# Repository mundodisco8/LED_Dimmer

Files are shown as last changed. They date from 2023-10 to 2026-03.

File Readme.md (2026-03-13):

# Gruffalo Fairy Light Dimmer

A simple LED light dimmer. My kids love fairy lights, but the ones we have are too bright to use them as sleep lights so I thought about churning up a quick PWM dimmer for them.

It's a simple project with simple goals:

* Do some electronics. I won't get the Noble prize on electronics for this one.
  * Subgoal: doing something in the incredibly sexy [After Dark](https://blog.oshpark.com/2019/10/10/introducing-our-after-dark-black-fr-4-service/) finish from OSH Park.
* Play with the Silicon Labs toolchain. I don't have any FW on my Github.
* Work with encoders. They are tactile and they are nice!
* Think a bit on user interfaces that children can use.
* See how far I can get without getting sued for copyright infringement.

The design acts as a motherboard for another of my projects, a [breakout board for the BGM220P BLE Module](https://github.com/mundodisco8/BGM220P-Breakout).

This is more or less how it looks like. The renders are done with pcb2blender, and it doesn't handle transparent soldermasks yet, so it's not showing the underlying copper base.

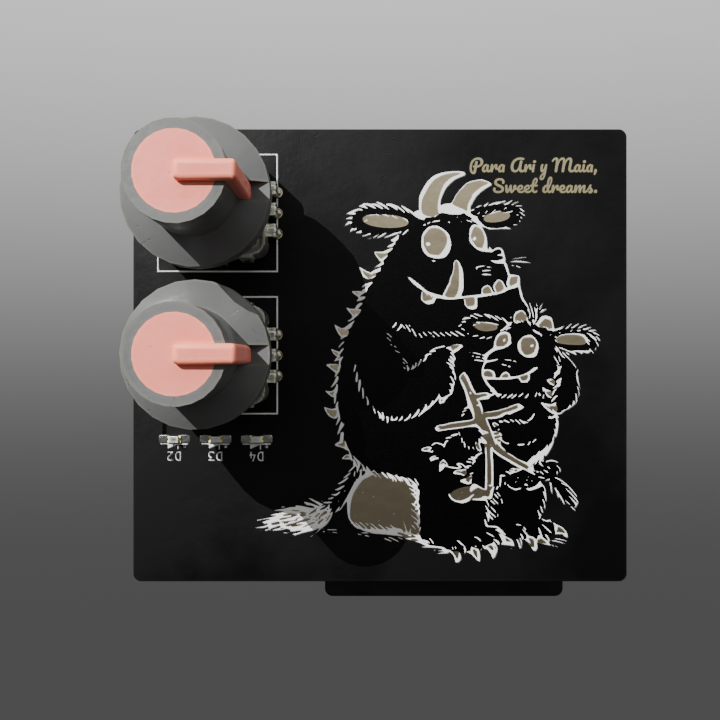
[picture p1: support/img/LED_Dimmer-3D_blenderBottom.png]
Bottom
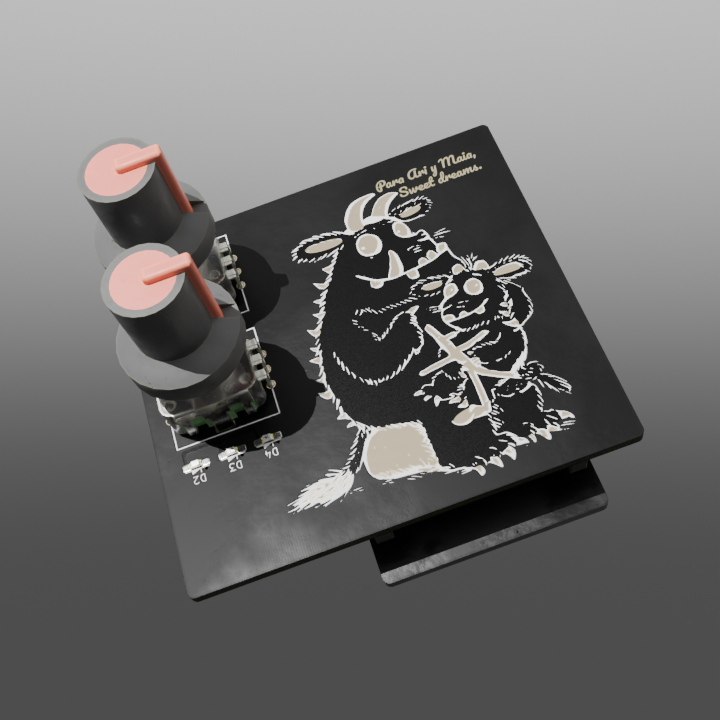
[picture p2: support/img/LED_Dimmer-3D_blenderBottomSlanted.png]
Bottom Slanted


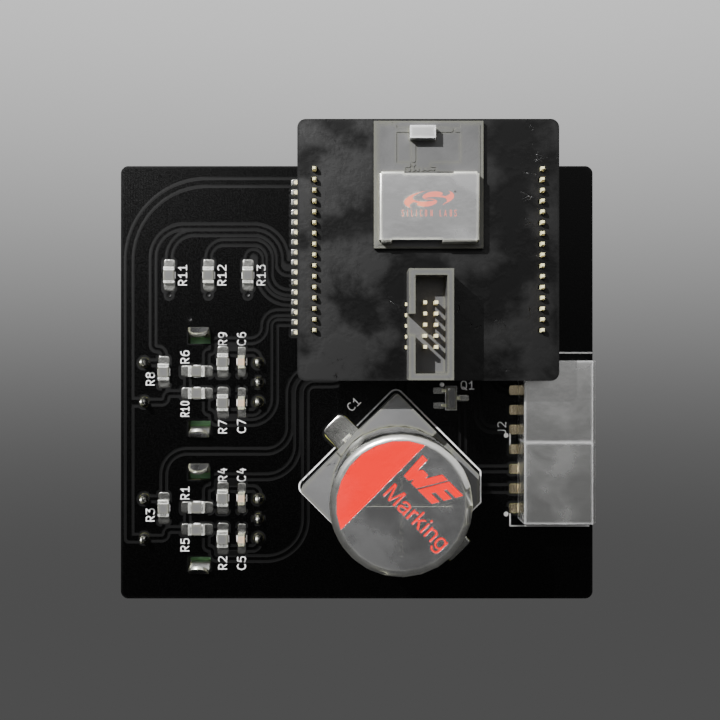
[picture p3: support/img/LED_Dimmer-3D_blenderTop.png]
Top
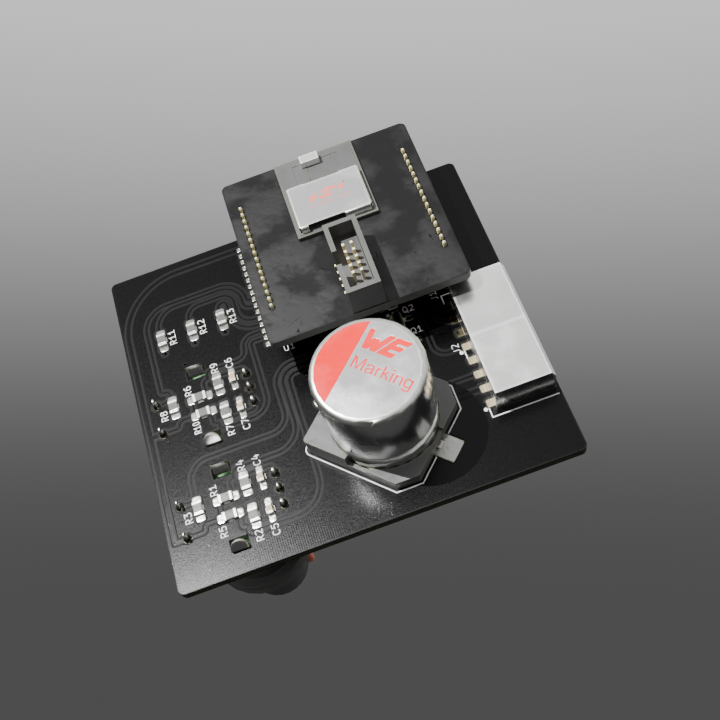
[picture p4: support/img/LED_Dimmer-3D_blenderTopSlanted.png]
Top Slanted


## Working with this project.

It has two elements:

* The hardware is included as a KiCad project. All the files needed are in the `hardware` folder. Make sure you read the [`Readme.md`](hardware/Readme.md) file present there if you want to open it or modify something.
* The firmware is provided as a Simplicity Studio project (Silicon Labs' IDE). You can find it in the `src` folder. Like the HW project, check the [`Readme.md`](src/readme.md) file to get more details about it.

## Tools I'm Using / Stuff I'm Stealing.

Made with:

* KiCad for the HW design, Simplicity Studio / VS Code for the Firmware.
* Unity for unit testing.
* Inkscape, for the art manipulation.
* Fusion360, for 3D model generation, as a source for my Fab layers and for the enclosure.
* Blender + [pcb2blender](https://github.com/30350n/pcb2blender), to generate my renders.
* I'm using [KiBot](https://github.com/INTI-CMNB/KiBot) as the main tool in my CI/CD pipeline.
* I used the Pacifico font in some text elements in the PCB ([link](https://fonts.google.com/specimen/Pacifico))

Things I definitely didn't do:

* The art, taken from [certain children's book authors](https://www.gruffalo.com/).

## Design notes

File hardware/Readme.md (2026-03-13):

# Readme

## LED Dimmer PCB

List of things that are interesting to know in order to work with this project.

* This commit uses KiCad 8.0.5
* It uses an unusual font for some text elements. It's Pacifico ([can be obtained here](https://fonts.google.com/specimen/Pacifico), and a copy is left in the `resources/fonts` folder as KiBot needs it).

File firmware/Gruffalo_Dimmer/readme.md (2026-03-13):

# LED Dimmer Firmware

This folder contains the Firmware project for the LED Dimmer. The project included is targeting a BGM220PWGA Module, but it could be compiled for other SoCs / Modules.

## Getting Started

The project is based on the Empty-SOC example.

It uses the 2024.6.1 SDK and GCC 12.2.1. In my experience, it's not worth to try to update the project to a newer SDK, as it always ends in tears. So one option would be to replicate the toolchain setup (specially the SDK version, the compiler is not that critical), or to get whatever is the latest and then start with a `Bluetooh SoC-Empty` project. If doing the latter, just overwrite your `app.c` with the one from the project, copy the `src` and `inc` folders (just to be specific, the `src/src` and `src/inc` folders) and make sure you add `inc` to the `include` path of the project (left click in the project, `C/C++ Build`, `Settings`, ` GNU ARM C Compiler`, `Includes`, `Include paths (-l)`).

Finally, it's a matter of preference, but I like to set all the warnings in my code, and disable all the warnings in the SDK code (as I can't do much to fix them, really). To do that, left click in the project, properties, C/C++ Build, Settings and in Tool Settings, GNU ARM C Compiler (And Assembler), remove `all warnings` and `extra warnings` and enable `Inhibit all warnings`. Then in my `inc` and `src` folders, and in `app.c`, do the same, but enable the relevant flags. **Do it in this order, or the general changes will inhibit your source code warnings**.

One of the SDK was triggering 70+ Code Analysis warnings (different than GCC warnings). To silence them, check the relevant item in Simplicity Studio settings (Window, Preferences, C/C++, Code Analysis). Double click in the warning to suppress and you can enter a pattern for filenames to be ignored. You have to do it for each static analysis warning, but there aren't that many.

### Importing the project.

The best way to import the project is

## Changes to the Empty Project

### Software Components:

#### Clock Manager

The new SDK didn't configure the clocks of my BLE module correctly and it would assert in the BT initialisation. I changed the `Clock Manager` settings, enabling the `HFXO Settings`, and leaving everything as default (XTAL Mode, 38.4MHz, 140, 50), leaving the `LFXO Settings` disabled, setting the `LFRCO Settings` to `High Precission` and finally, in `Clock Tree Settings`, picking `HXFO` as the `Default Clock Source Selection for HF clock branches` (`LFRCO` for the `LF clock branches`).

#### IO Stream: EUSART

Installed this module to get serial debugging. Set the EUART as you require, and then set the `RX` and `TX` Pins to `PB00` and `PA00` respectively.

#### Log

Used to get nice log output. Configuring it is a matter of preference, so do whatever you prefer here.

#### GPIOINT

Needed to handle the button and rotary interrupts. Doesn't neet to be configured.

#### Timer

The module is already installed, but you can set the number of software timers you need in `Bluetooth Stack Configuration` in `Bluetooth Core`.

#### Bootloader Application Interface / Bluetooth In-Place OTA

Remove them if you don't want to faf around with bootloaders. If I'm changing the software, I will need the device removed to play with it so I might as well leave it with the latest, instead of needing to do BLE updates. Maybe one day I have 20 of these around the house and it makes sense to do OTAs.

#### Rail Utility, PTI

PTI it's a radio debugging feature. I'm not going to use it, but it generates warnings if not configured. Set the `SL_RAIL_UTILITY_PTI` module to `None`.

### Pins

Use the Pin Tool to set:

* UART Logging:
  * PA00 as `EUART0_TX`.
  * PB00 as `EUART0_RX`.
* Encoder 0:
  * PA06 as `GPIO Mode` with `btn0` as `Custom Pin Name`.
  * PA07 as `GPIO Mode` with `quad0_0` as `Custom Pin Name`.
  * PA08 as `GPIO Mode` with `quad0_1` as `Custom Pin Name`.
* Encoder 1:
  * PC04 as `GPIO Mode` with `btn1` as `Custom Pin Name`.
  * PA04 as `GPIO Mode` with `quad1_0` as `Custom Pin Name`.
  * PA05 as `GPIO Mode` with `quad1_1` as `Custom Pin Name`.
* PWM:
  * PC2 as `TIMER0_CC0` with `PWM0` as `Custom Pin Name`
  * PC1
  * PC0

## Designing the GATT Database

The SOC-empty example implements a basic GATT database. GATT definitions (services/characteristics) can be extended using the GATT Configurator, which can be found under Advanced Configurators in the Software Components tab of the Project Configurator. To open the Project Configurator, open the .slcp file of the project.

Opening GATT Configurator

To learn how to use the GATT Configurator, see [UG438: GATT Configurator User’s Guide for Bluetooth SDK v3.x](https://www.silabs.com/documents/public/user-guides/ug438-gatt-configurator-users-guide-sdk-v3x.pdf).

## Responding to Bluetooth Events

A Bluetooth application is event driven. The Bluetooth stack generates events e.g., when a remote device connects or disconnects or when it writes a characteristic in the local GATT database. The application has to handle these events in the `sl_bt_on_event()` function. The prototype of this function is implemented in *app.c*. To handle more events, the switch-case statement of this function is to be extended. For the list of Bluetooth events, see the online [Bluetooth API Reference](https://docs.silabs.com/bluetooth/latest/).

## Implementing Application Logic

Additional application logic has to be implemented in the `app_init()` and `app_process_action()` functions. Find the definitions of these functions in *app.c*. The `app_init()` function is called once when the device is booted, and `app_process_action()` is called repeatedly in a while(1) loop. For example, you can poll peripherals in this function. To save energy and to have this function called at specific intervals only, for example once every second, use the services of the [Sleeptimer](https://docs.silabs.com/gecko-platform/latest/service/api/group-sleeptimer). If you need a more sophisticated application, consider using RTOS (see [AN1260: Integrating v3.x Silicon Labs Bluetooth Applications with Real-Time Operating Systems](https://www.silabs.com/documents/public/application-notes/an1260-integrating-v3x-bluetooth-applications-with-rtos.pdf)).

## Features Already Added to the SOC-Empty Application

The SOC-Empty application is ***almost*** empty. It implements a basic application to demonstrate how to handle events, how to use the GATT database, and how to add software components.

* A simple application is implemented in the event handler function that starts advertising on boot (and on connection_closed event). This makes it possible for remote devices to find the device and connect to it.
* A simple GATT database is defined by adding Generic Access and Device Information services. This makes it possible for remote devices to read out some basic information such as the device name.
* The OTA DFU software component is added, which extends both the event handlers (see *sl_ota_dfu.c*) and the GATT database (see *ota_dfu.xml*). This makes it possible to make Over-The-Air Device-Firmware-Upgrade without any additional application code.

## Testing the SOC-Empty Application

As described above, an empty example does nothing except advertising and letting other devices connect and read its basic GATT database. To test this feature, do the following:

1. Build and flash the SoC-Empty example to your device.
2. Make sure a bootloader is installed. See the Troubleshooting section.
3. Download the **EFR Connect** smartphone app, available on [iOS](https://apps.apple.com/us/app/efr-connect/id1030932759) and [Android](https://play.google.com/store/apps/details?id=com.siliconlabs.bledemo).
4. Open the app and choose the Bluetooth Browser.
   EFR Connect start screen
5. Now you should find your device advertising as "Empty Example". Tap **Connect**.
   Bluetooth Browser
6. The connection is opened, and the GATT database is automatically discovered. Find the device name characteristic under Generic Access service and try to read out the device name.
   GATT database of the device

## Troubleshooting

### Bootloader Issues

Note that Example Projects do not include a bootloader. However, Bluetooth-based Example Projects expect a bootloader to be present on the device in order to support device firmware upgrade (DFU). To get your application to work, you should either
- flash the proper bootloader or
- remove the DFU functionality from the project.

**If you do not wish to add a bootloader**, then remove the DFU functionality by uninstalling the *Bootloader Application Interface* software component -- and all of its dependants. This will automatically put your application code to the start address of the flash, which means that a bootloader is no longer needed, but also that you will not be able to upgrade your firmware.

**If you want to add a bootloader**, then either
- Create a bootloader project, build it and flash it to your device. Note that different projects expect different bootloaders:
  - for NCP and RCP projects create a *BGAPI UART DFU* type bootloader
  - for SoC projects on Series 2 devices create a *Bluetooth Apploader OTA DFU* type bootloader

- or run a precompiled Demo on your device from the Launcher view before flashing your application. Precompiled demos flash both bootloader and application images to the device. Flashing your own application image after the demo will overwrite the demo application but leave the bootloader in place.
  - For NCP and RCP projects, flash the *Bluetooth - NCP* demo.
  - For SoC projects, flash the *Bluetooth - SoC Thermometer* demo.

**Important Notes:**
- when you flash your application image to the device, use the *.hex* or *.s37* output file. Flashing *.bin* files may overwrite (erase) the bootloader.

- On Series 2 devices SoC example projects require a *Bluetooth Apploader OTA DFU* type bootloader by default. This bootloader needs a lot of flash space and does not fit into the regular bootloader area, hence the application start address must be shifted. This shift is automatically done by the *Apploader Support for Applications* software component, which is installed by default. If you want to use any other bootloader type, you should remove this software component in order to shift the application start address back to the end of the regular bootloader area. Note, that in this case you cannot do OTA DFU with Apploader, but you can still implement application-level OTA DFU by installing the *Application OTA DFU* software component instead of *In-place OTA DFU*.

For more information on bootloaders, see [UG103.6: Bootloader Fundamentals](https://www.silabs.com/documents/public/user-guides/ug103-06-fundamentals-bootloading.pdf) and [UG489: Silicon Labs Gecko Bootloader User's Guide for GSDK 4.0 and Higher](https://cn.silabs.com/documents/public/user-guides/ug489-gecko-bootloader-user-guide-gsdk-4.pdf).

### Programming the Radio Board

Before programming the radio board mounted on the mainboard, make sure the power supply switch is in the AEM position (right side) as shown below.

Radio board power supply switch

## Resources

[Bluetooth Documentation](https://docs.silabs.com/bluetooth/latest/)

[UG103.14: Bluetooth LE Fundamentals](https://www.silabs.com/documents/public/user-guides/ug103-14-fundamentals-ble.pdf)

[QSG169: Bluetooth SDK v3.x Quick Start Guide](https://www.silabs.com/documents/public/quick-start-guides/qsg169-bluetooth-sdk-v3x-quick-start-guide.pdf)

[UG434: Silicon Labs Bluetooth ® C Application Developer's Guide for SDK v3.x](https://www.silabs.com/documents/public/user-guides/ug434-bluetooth-c-soc-dev-guide-sdk-v3x.pdf)

[Bluetooth Training](https://www.silabs.com/support/training/bluetooth)

## Report Bugs & Get Support

You are always encouraged and welcome to report any issues you found to us via [Silicon Labs Community](https://www.silabs.com/community).

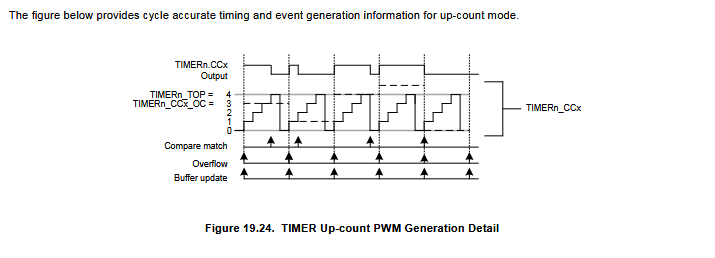
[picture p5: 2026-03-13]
doc/PWM And Breathe Effect/img/PWMCycleAccurate.png

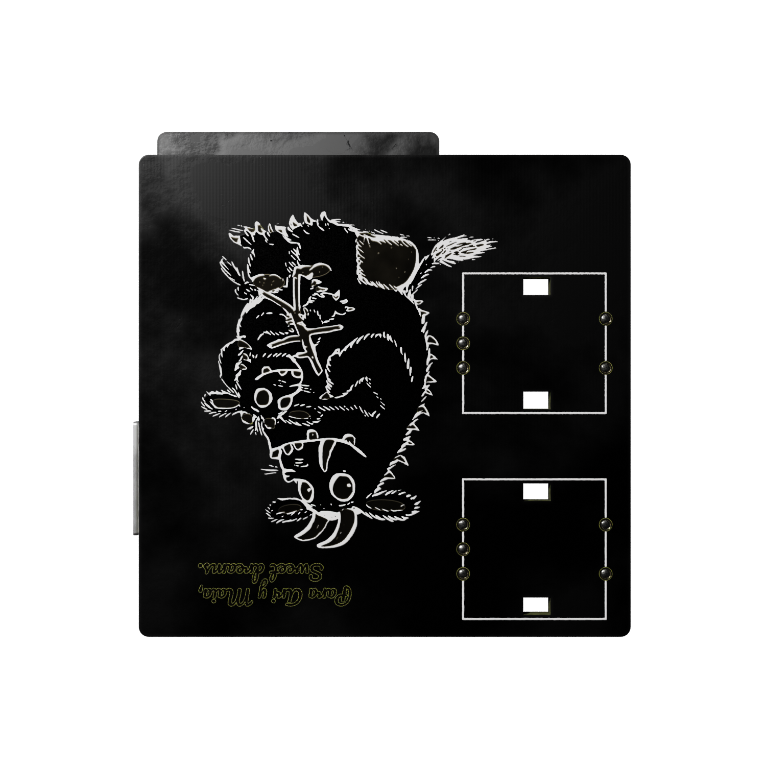
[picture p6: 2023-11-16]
support/img/LED_Dimmer-3D_blenderBottom_BottomTexture.png

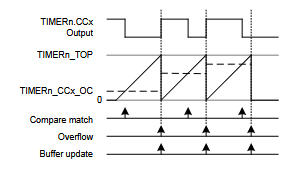
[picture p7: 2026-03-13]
doc/PWM And Breathe Effect/img/PWMGraph.png

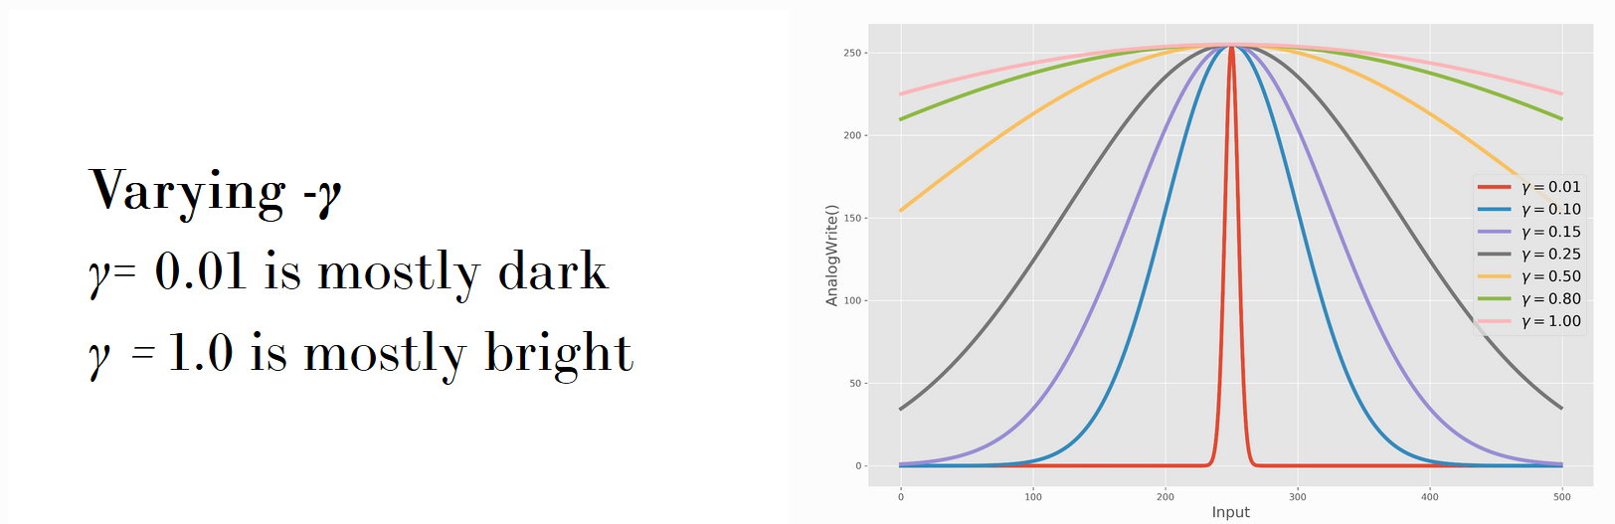
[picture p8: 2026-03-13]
doc/PWM And Breathe Effect/img/GaussianBreatheGamma.png

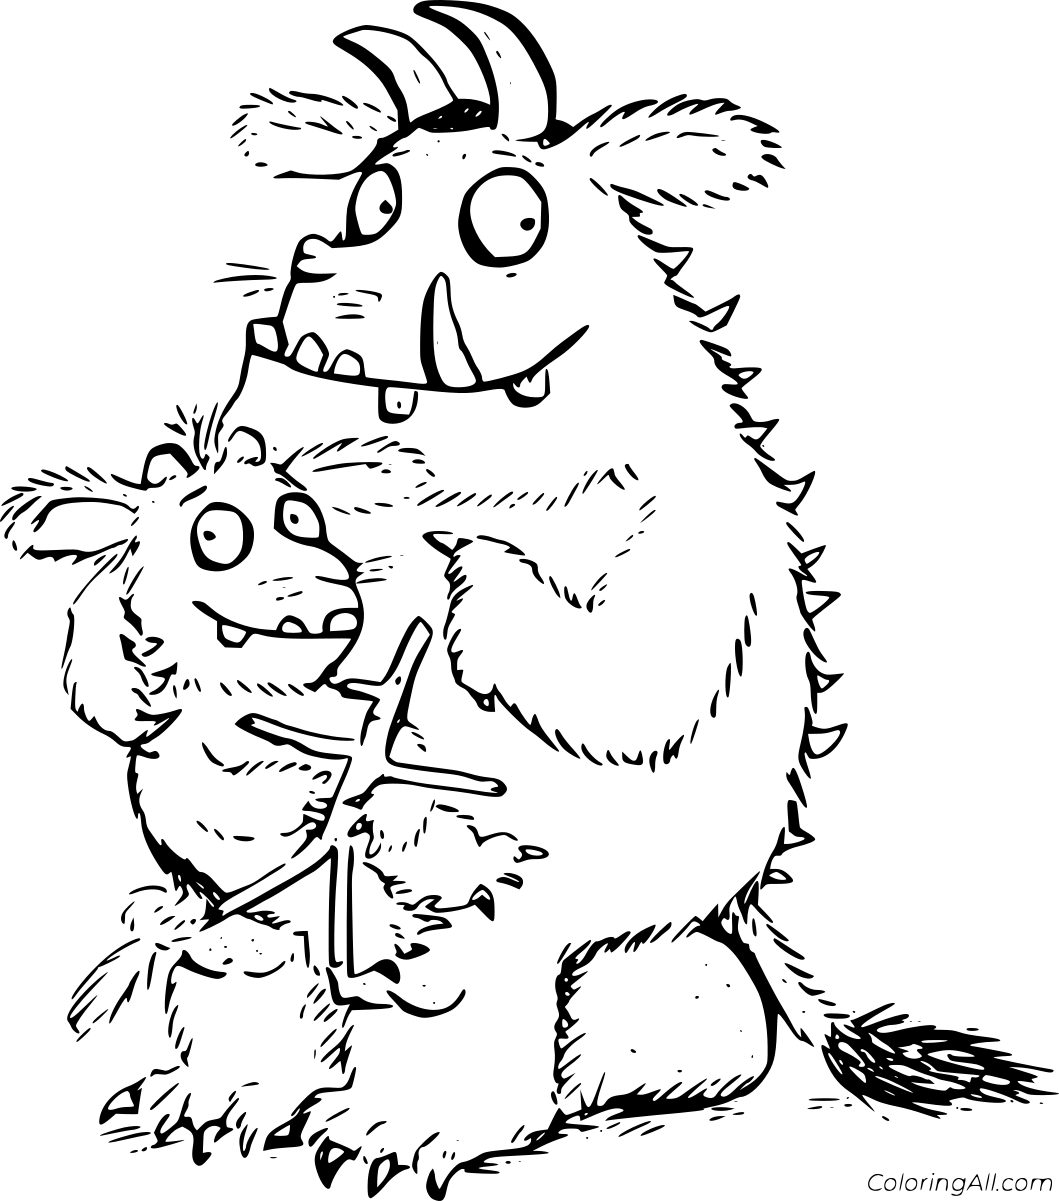
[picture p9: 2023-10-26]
support/Gruffalo-and-His-Child.png

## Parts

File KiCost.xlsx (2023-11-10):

Prj: | Gruffalo Dimmer |  |  |  |  |  |  | Board Qty: | 2
Co.: |  |  |  |  |  |  |  | Unit Cost: | $10.25
Prj date: | 10/11/2023 17:34:35 |  |  |  |  |  |  | Total Cost: | $20.50 |  |  |  |  | $22.24 | 13 of 13 parts found
$ date: | 2023-11-10 17:35:06
Global Part Info |  |  |  |  |  |  |  |  |  | Digi-Key
Refs | Value | Footprint | Manf | Manf# | Qty |  |  | Unit$ | Ext$ | Avail | Purch | Unit$ | MOQ | Ext$ | Cat#
C1 | 1000μF | Electrolytic Cap - ⌀16mm, h17mm - SMD - Handsolder | Wurth Electronic | 865080663020 (https://www.we-online.com/components/products/datasheet/865080663020.pdf) | 2 | 0 | 0 | $2.920 | $5.84 | 602 | 2 | $2.920 | 1 | $5.84 | 732-8465-1-ND (https://www.digikey.com/en/products/detail/würth-elektronik/865080663020/5728060)
C2 | 330nF | 0805-C_Handsolder | Samsung | 3369310 (https://product.samsungsem.com/mlcc/CL10B334KO8NNN.do) | 2 | 0 | 3 | $0.190 | $0.38 | 88960 | 5 | $0.190 | 1 | $0.95 | 311-1888-1-ND (https://www.digikey.com/en/products/detail/yageo/CC0805KKX7R9BB334/5195294)
C3 | 100nF | 0603-1.6x0.8mm-C_Handsolder | Samsung | CL10B104KB8NNWC | 2 | 50 | 0 |  |  | 7199544 | -48 |  | 1 |  | 1276-1935-1-ND (https://www.digikey.com/en/products/detail/samsung-electro-mechanics/CL10B104KB8NNWC/3887593)
C4-C7 | 10nF | 0603-1.6x0.8mm-C_Handsolder | Samsung | CL10B103KB8NNNC | 8 |  | 2 | $0.025 | $0.20 | 5356438 | 10 | $0.025 | 1 | $0.25 | 1276-1009-1-ND (https://www.digikey.com/en/products/detail/samsung-electro-mechanics/CL10B103KB8NNNC/3886667)
D1#1 | CUS08F30,H3F - p1/2 | D_SOD-323_HandSoldering | Toshiba | CUS08F30 (https://toshiba.semicon-storage.com/info/CUS08F30_datasheet_en_20140414.pdf?did=9019&prodName=CUS08F30) | 2 |  | 3 | $0.320 | $0.64 | 660372 | 5 | $0.320 | 1 | $1.60 | CUS08F30H3FCT-ND (https://www.digikey.com/en/products/detail/toshiba-semiconductor-and-storage/CUS08F30-H3F/5114298)
J1 | Molex PicoBlade 53261-0871 1x08 | Receptacle - Molex PicoBlade - SMD Right Angle 1x08 | Molex | 532610871 (https://www.molex.com/molex/products/part-detail/pcb_headers/0532610871) | 2 |  | 0 | $0.930 | $1.86 | 12222 | 2 | $0.930 | 1 | $1.86 | WM7626CT-ND (https://www.digikey.com/en/products/detail/molex/0532610871/699100)
J2 | PicoBlade_510210800_1x08 |  | Molex | 0510210800 (https://www.molex.com/content/dam/molex/molex-dot-com/products/automated/en-us/salesdrawingpdf/510/51021/510210800_sd.pdf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) | 2 |  | 0 | $0.350 | $0.70 | 70597 | 2 | $0.350 | 1 | $0.70 | WM1726-ND (https://www.digikey.com/en/products/detail/molex/0510210800/242848)
M1-M8 | 500798001 |  | Molex | 0500798000 (https://www.molex.com/content/dam/molex/molex-dot-com/products/automated/en-us/salesdrawingpdf/500/50079/500798001_sd.pdf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) | 16 |  | 4 | $0.040 | $0.64 | 447586 | 20 | $0.040 | 1 | $0.80 | WM1142CT-ND (https://www.digikey.com/en/products/detail/molex/0500798000/467822)
Q1-Q3 | 2N7002K-7 | SOT-23 - NMOS - GDS | Diodes Inc. | 2N7002K-7 (https://www.diodes.com/assets/Datasheets/2N7002K.pdf) | 6 | 2 | 2 | $0.220 | $1.32 | NonStk | 6 | $0.220 | 1 | $1.32 | 2N7002K-7DICT-ND (https://www.digikey.com/en/products/detail/diodes-incorporated/2N7002K-7/1934378)
R1-R10 | 10kΩ | 0805-R_Handsolder | Yageo | RC0805JR-0710KL | 20 | 0 | 0 | $0.022 | $0.44 | 725857 | 20 | $0.022 | 1 | $0.44 | 311-10KARCT-ND (https://www.digikey.com/en/products/detail/yageo/RC0805JR-0710KL/728241)
SW1,SW2 | N/A | Rotary Encoder - PEC11R - ∅11mm | Bourns | PEC11R-4115F-S0018 (https://www.bourns.com/docs/product-datasheets/pec11r.pdf?sfvrsn=bb617cbf_12) | 4 | 0 | 0 | $2.120 | $8.48 | 11959 | 4 | $2.120 | 1 | $8.48 | PEC11R-4115F-S0018-ND (https://www.digikey.com/en/products/detail/bourns-inc/PEC11R-4115F-S0018/4499666)
U1 | BGM220P | BGM220P_Header_SMD | Silabs | BGM220PC22WGA (https://www.silabs.com/documents/public/data-sheets/bgm220p-datasheet.pdf) | 2 | 2 | 0 |  |  | 1686 | 0 | $0.000 | 1 | $0.00 | 336-BGM220PC22WGA2RCT-ND (https://www.digikey.com/en/products/detail/silicon-labs/BGM220PC22WGA2R/12317146)
U2 | L78L33A | SO-8 - 6x4.9mm p1.27mm - L78L33A - ST | ST | L78L33ACD13TR (https://www.st.com/resource/en/datasheet/l78l.pdf) | 2 | 2 | 0 |  |  | 2500 | 0 | MOQ=2500 | 2500 |  | 5060-L78L33ACD13TR-ND (https://www.digikey.com/en/products/detail/maxvision/L78L33ACD13TR/19199901)
 |  |  |  |  |  |  |  | Total Purchase: | $22.24 | Buy here (https://www.digikey.com/ordering/shoppingcart) | 10 of 13 parts purchased |  |  | $22.24
KiCost® v1.1.18 |  |  |  |  |  |  |  | Purchase description: |  |  | #N/A

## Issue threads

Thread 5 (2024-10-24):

Encoder is not wired correctly!

mundodisco8, 2024-10-24:
I was puzzled by the fact that the encoder wouldn't go to 0V. At first I thought it was me setting the μC pin to internal pull-up, but it turns out I wired it the wrong way round! This is what I did
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

And this is what I should have done

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

Notice how the resistors are not connected on the same node. Thankfully, it's easy to fix on the boards I already made, but we will have to fix it.

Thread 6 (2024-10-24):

The connector is completely off!

mundodisco8, 2024-10-24:
The connector I chose is not suitable for the project. The wires the led strips I got are something like AWG 22, and the crimps for this connector are max AWG 26.

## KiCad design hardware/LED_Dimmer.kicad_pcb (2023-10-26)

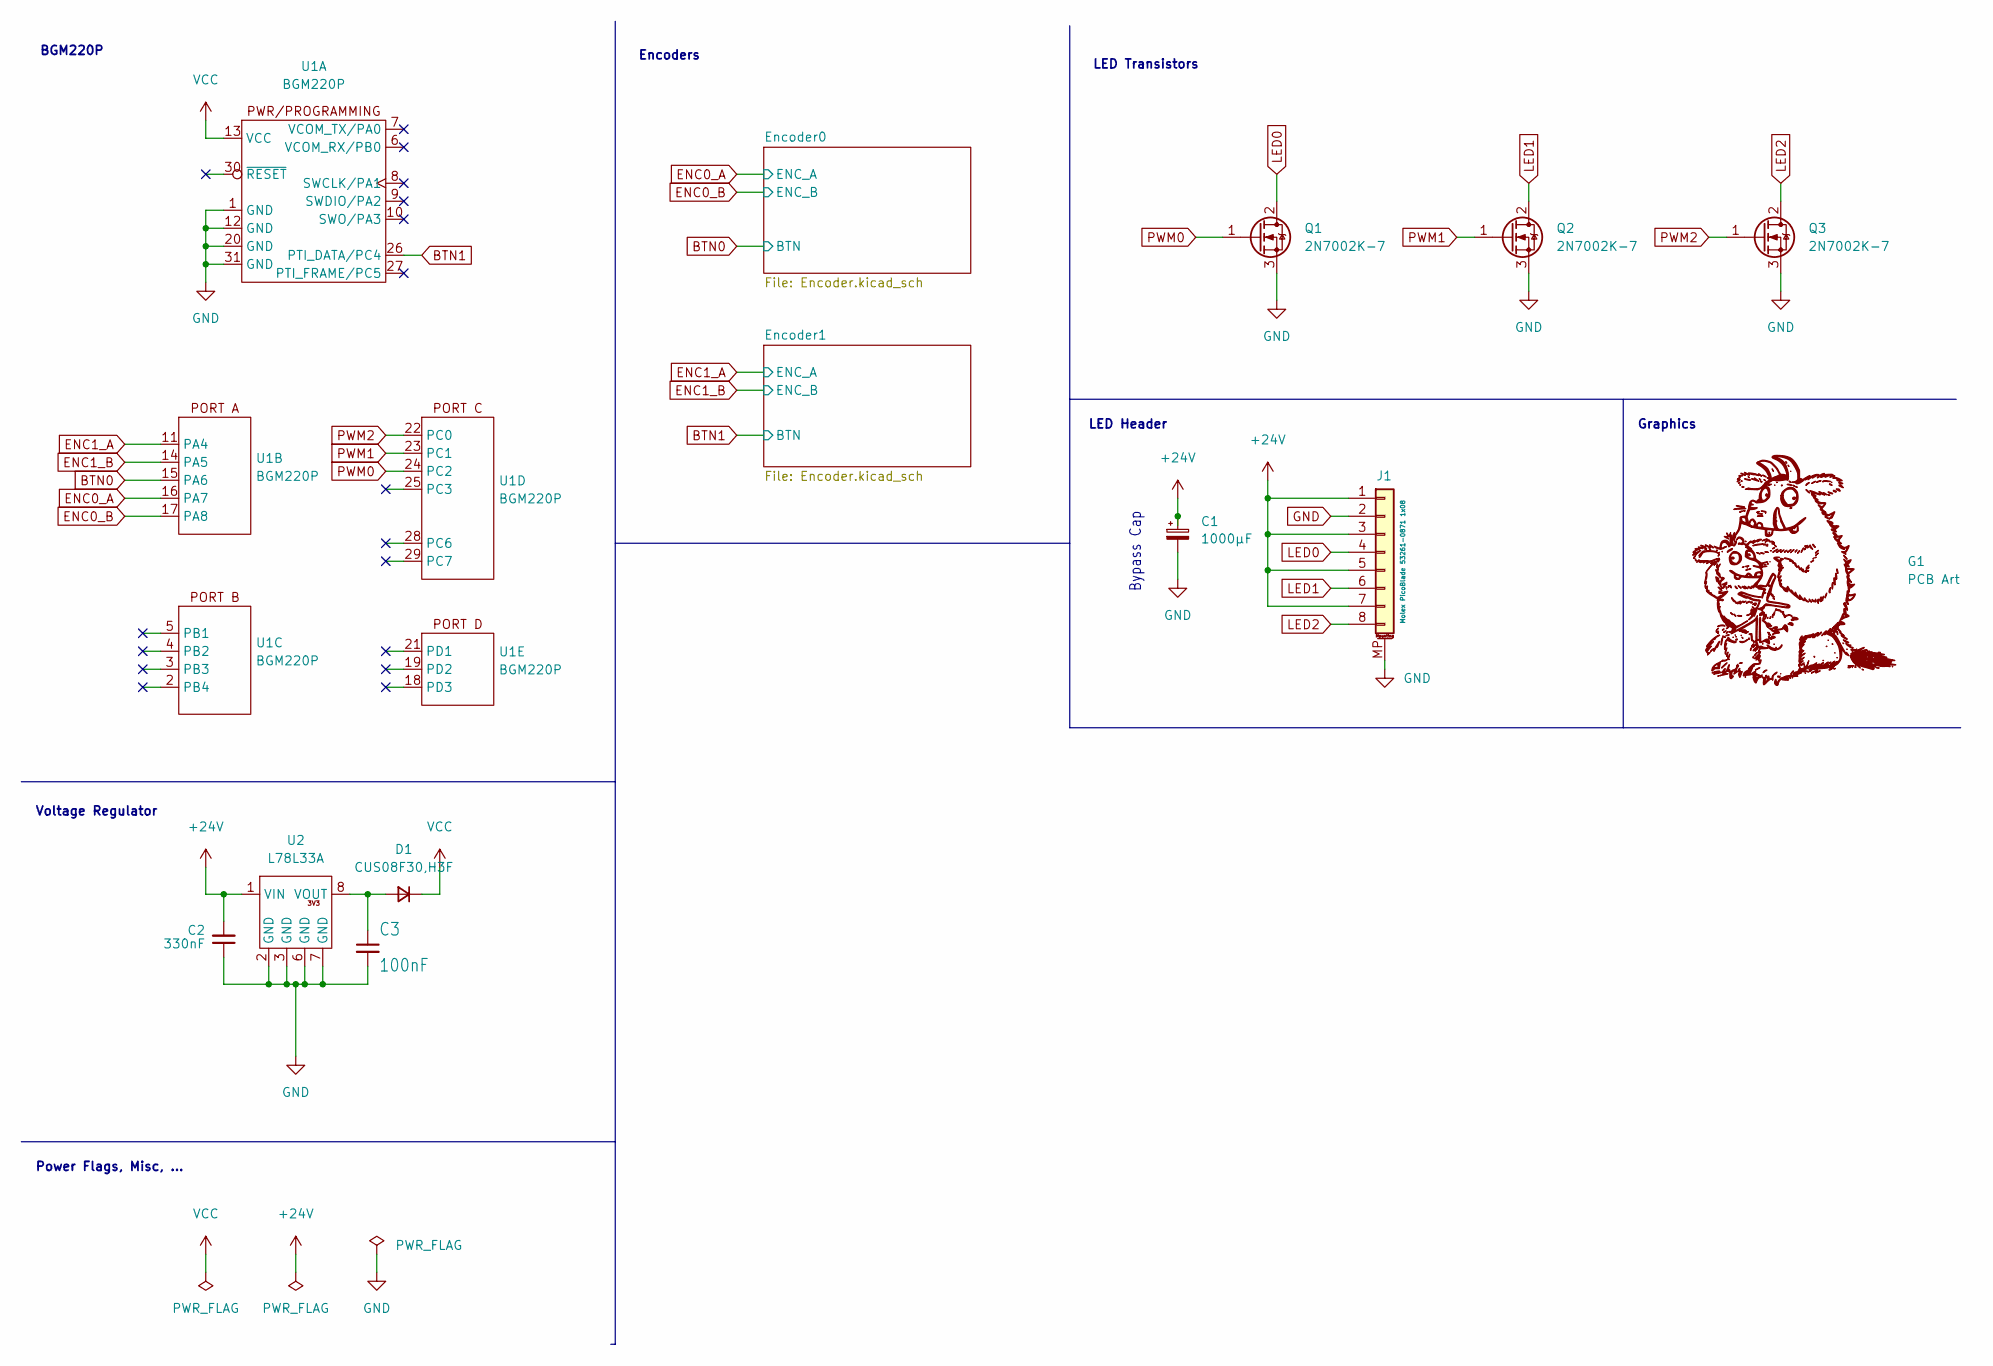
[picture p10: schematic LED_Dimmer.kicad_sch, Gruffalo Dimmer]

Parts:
C1: 1000μF; Electrolytic Cap - ⌀16mm, h17mm - SMD - Handsolder; Tolerance ±20%; MPN 865080663020; Digikey PN 732-8465-1-ND
C2: 330nF; 0805-C_Handsolder; Tolerance X7R; MPN 3369310; Digikey PN 1276-1123-1-ND
C3: 100nF; 0603-1.6x0.8mm-C_Handsolder; Tolerance X7R; MPN CL10B104KB8NNWC; Digikey PN 1276-1935-1-ND
D1: CUS08F30,H3F; D_SOD-323_HandSoldering; MPN CUS08F30,H3F; Digikey PN CUS08F30H3FCT-ND
G1: PCB Art; Gruffalo_Art
J1: Molex PicoBlade 53261-0871 1x08; Receptacle - Molex PicoBlade - SMD Right Angle 1x08; MPN 532610871; Digikey PN WM7626CT-ND
Q1, Q2, Q3: 2N7002K-7; SOT-23 - NMOS - GDS; MPN 2N7002K-7; Digikey PN 2N7002K-7DICT-ND
U1: BGM220P; BGM220P_Header_SMD; MPN BGM220PC22WGA; Digikey PN 336-BGM220PC22WGA2-ND
U2: L78L33A; SO-8 - 6x4.9mm p1.27mm - L78L33A - ST; MPN L78L33ACD13TR; Digikey PN 497-1199-1-ND

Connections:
+24V: C1.1, C2.2, J1.1, J1.3, J1.5, J1.7, U2.1 (VIN)
BTN0: U1.15 (PA6); also elsewhere on the board
BTN1: U1.26 (PTI_DATA/PC4); also elsewhere on the board
ENC0_A: U1.16 (PA7); also elsewhere on the board
ENC0_B: U1.17 (PA8); also elsewhere on the board
ENC1_A: U1.11 (PA4); also elsewhere on the board
ENC1_B: U1.14 (PA5); also elsewhere on the board
GND: C1.2, C2.1, C3.2, J1.2, J1.MP (MountPin), Q1.3 (S), Q2.3 (S), Q3.3 (S), U1.1 (GND), U1.12 (GND), U1.20 (GND), U1.31 (GND), U2.2 (GND), U2.3 (GND), U2.6 (GND), U2.7 (GND); also elsewhere on the board
LED0: J1.4, Q1.2 (D)
LED1: J1.6, Q2.2 (D)
LED2: J1.8, Q3.2 (D)
unnamed: C3.1, D1.2 (A), U2.8 (VOUT)
PWM0: Q1.1 (G), U1.24 (PC2)
PWM1: Q2.1 (G), U1.23 (PC1)
PWM2: Q3.1 (G), U1.22 (PC0)
VCC: D1.1 (K), U1.13 (VCC); also elsewhere on the board

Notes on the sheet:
Power Flags, Misc, ...
Voltage Regulator
Encoders
BGM220P
Bypass Cap
LED Transistors
LED Header
Graphics

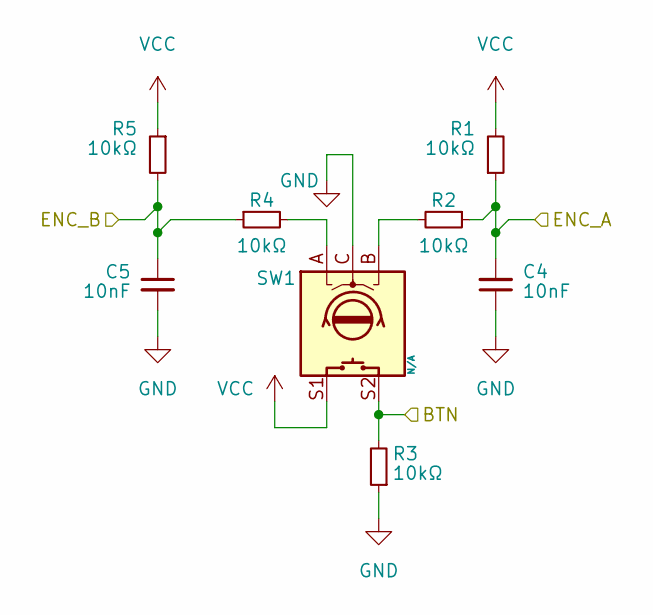
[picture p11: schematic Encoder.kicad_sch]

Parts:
C4, C5: 10nF; 0603-1.6x0.8mm-C_Handsolder; Tolerance X7R; MPN CL10B103KB8NNNC; Digikey PN 1276-1009-1-ND
R1, R2, R3, R4, R5: 10kΩ; 0805-R_Handsolder; MPN RC0805JR-0710KL; Digikey PN 311-10KARCT-ND
SW1: N/A; Rotary Encoder - PEC11R - ∅11mm; MPN PEC11R-4115F-S0018; Digikey PN PEC11R-4115F-S0018-ND

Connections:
BTN0: R3.2, SW1.S2; also elsewhere on the board
ENC0_A: C4.2, R1.1, R2.1; also elsewhere on the board
ENC0_B: C5.1, R4.1, R5.2; also elsewhere on the board
GND: C4.1, C5.2, R3.1, SW1.C; also elsewhere on the board
unnamed: R2.2, SW1.B
unnamed: R4.2, SW1.A
VCC: R1.2, R5.1, SW1.S1; also elsewhere on the board

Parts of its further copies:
C6, C7: 10nF; 0603-1.6x0.8mm-C_Handsolder; Tolerance X7R; MPN CL10B103KB8NNNC; Digikey PN 1276-1009-1-ND
R6, R7, R8, R9, R10: 10kΩ; 0805-R_Handsolder; MPN RC0805JR-0710KL; Digikey PN 311-10KARCT-ND
SW2: N/A; Rotary Encoder - PEC11R - ∅11mm; MPN PEC11R-4115F-S0018; Digikey PN PEC11R-4115F-S0018-ND

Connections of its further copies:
BTN1: R8.2, SW2.S2; also elsewhere on the board
ENC1_A: C6.2, R6.1, R7.1; also elsewhere on the board
ENC1_B: C7.1, R9.1, R10.2; also elsewhere on the board
GND: C6.1, C7.2, R8.1, SW2.C; also elsewhere on the board
unnamed: R7.2, SW2.B
unnamed: R9.2, SW2.A
VCC: R6.2, R10.1, SW2.S1; also elsewhere on the board

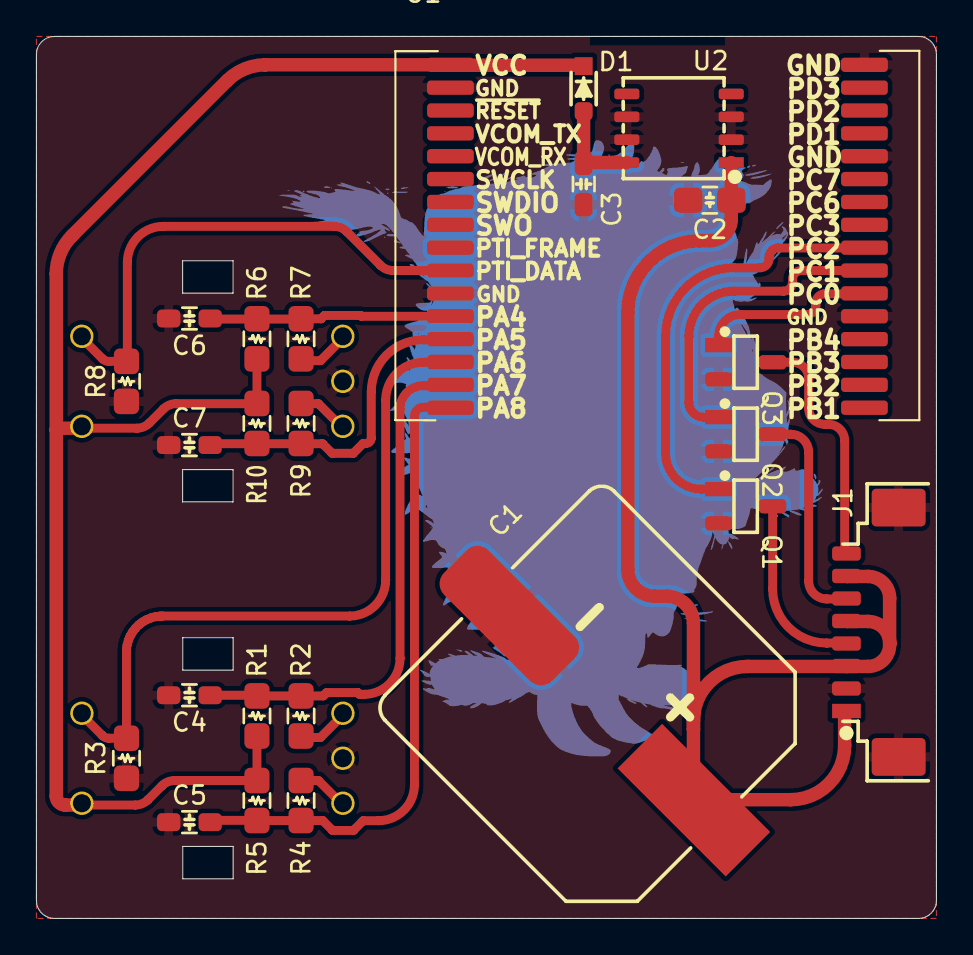
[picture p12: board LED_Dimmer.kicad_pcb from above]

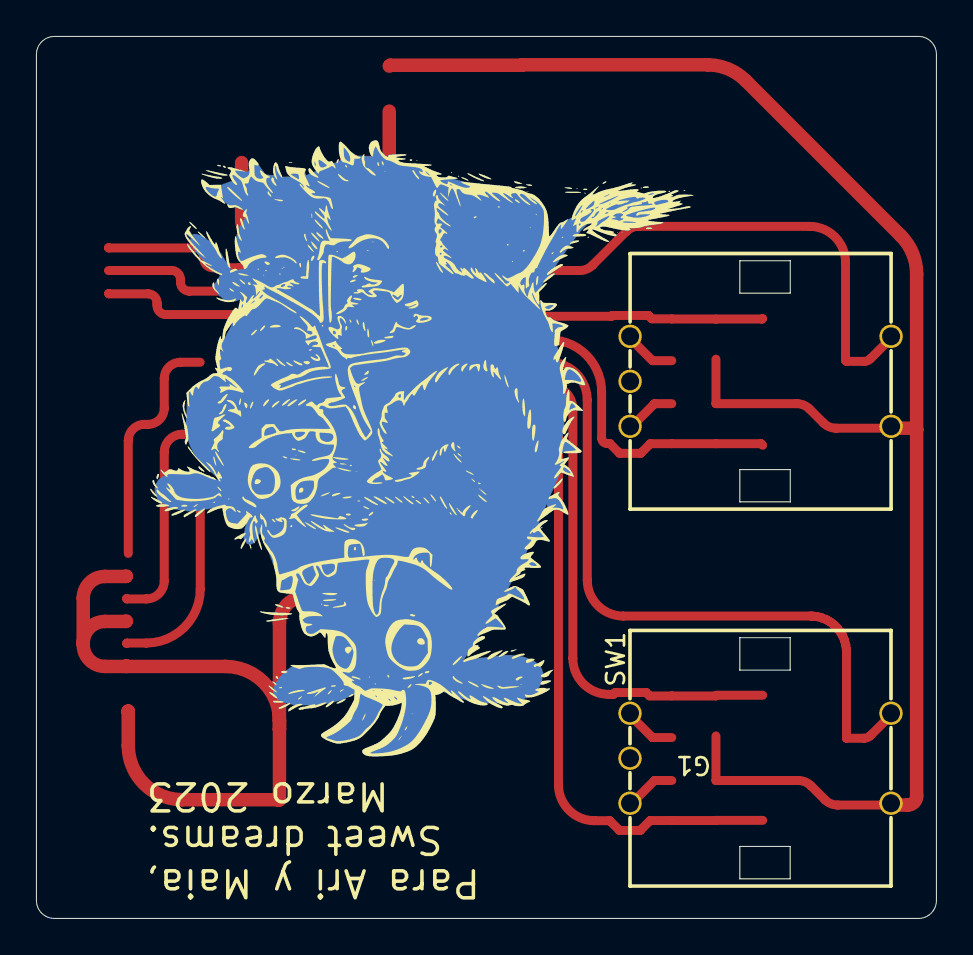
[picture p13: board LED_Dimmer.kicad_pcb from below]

Board: 2 copper layers, 50.0 x 49.0 mm, 27 parts (3 on the bottom side), 20 nets.

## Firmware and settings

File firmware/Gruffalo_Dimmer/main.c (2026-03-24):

/*****************************************************************************
 * @file
 * @brief main() function.
 *******************************************************************************
 * # License
 * <b>Copyright 2020 Silicon Laboratories Inc. www.silabs.com</b>
 *******************************************************************************
 *
 * SPDX-License-Identifier: Zlib
 *
 * The licensor of this software is Silicon Laboratories Inc.
 *
 * This software is provided 'as-is', without any express or implied
 * warranty. In no event will the authors be held liable for any damages
 * arising from the use of this software.
 *
 * Permission is granted to anyone to use this software for any purpose,
 * including commercial applications, and to alter it and redistribute it
 * freely, subject to the following restrictions:
 *
 * 1. The origin of this software must not be misrepresented; you must not
 *    claim that you wrote the original software. If you use this software
 *    in a product, an acknowledgment in the product documentation would be
 *    appreciated but is not required.
 * 2. Altered source versions must be plainly marked as such, and must not be
 *    misrepresented as being the original software.
 * 3. This notice may not be removed or altered from any source distribution.
 *
 ******************************************************************************/
#include "app.h"
#include "sl_component_catalog.h"
#include "sl_system_init.h"
#if defined(SL_CATALOG_POWER_MANAGER_PRESENT)
#include "sl_power_manager.h"
#endif  // SL_CATALOG_POWER_MANAGER_PRESENT
#if defined(SL_CATALOG_KERNEL_PRESENT)
#include "sl_system_kernel.h"
#else  // SL_CATALOG_KERNEL_PRESENT
#include "sl_system_process_action.h"
#endif  // SL_CATALOG_KERNEL_PRESENT

#include "em_emu.h"
#include "sl_power_manager_debug.h"
#include "timer_HW.h"
void my_events_callback(sl_power_manager_em_t from, sl_power_manager_em_t to);

bool sleepOnce = true;

#define EM_EVENT_MASK_ALL                                                                             \
    (SL_POWER_MANAGER_EVENT_TRANSITION_ENTERING_EM0 | SL_POWER_MANAGER_EVENT_TRANSITION_LEAVING_EM0 | \
     SL_POWER_MANAGER_EVENT_TRANSITION_ENTERING_EM1 | SL_POWER_MANAGER_EVENT_TRANSITION_LEAVING_EM1 | \
     SL_POWER_MANAGER_EVENT_TRANSITION_ENTERING_EM2 | SL_POWER_MANAGER_EVENT_TRANSITION_LEAVING_EM2)

sl_power_manager_em_transition_event_handle_t event_handle;
sl_power_manager_em_transition_event_info_t event_info = {
    .event_mask = EM_EVENT_MASK_ALL,
    .on_event   = my_events_callback,
};

extern bool sleepFlag;
int main(void) {
    // Initialize Silicon Labs device, system, service(s) and protocol stack(s).
    // Note that if the kernel is present, processing task(s) will be created by
    // this call.
    sl_system_init();

    // Turn on DCDC regulator
    EMU_DCDCInit_TypeDef dcdcInit = EMU_DCDCINIT_DEFAULT;
    EMU_DCDCInit(&dcdcInit);
    // Initialize the application. For example, create periodic timer(s) or
    // task(s) if the kernel is present.
    app_init();

    sl_power_manager_subscribe_em_transition_event(&event_handle, &event_info);
    // sl_power_manager_debug_print_em_requirements();

#if defined(SL_CATALOG_KERNEL_PRESENT)
    // Start the kernel. Task(s) created in app_init() will start running.
    sl_system_kernel_start();
#else  // SL_CATALOG_KERNEL_PRESENT
    while (1) {
        // Do not remove this call: Silicon Labs components process action routine
        // must be called from the super loop.
        sl_system_process_action();

        // Application process.
        app_process_action();

#if defined(SL_CATALOG_POWER_MANAGER_PRESENT)
        // Let the CPU go to sleep if the system allows it.
        // sl_power_manager_sleep();
#endif
    }
#endif  // SL_CATALOG_KERNEL_PRESENT
}

#include "app_log.h"
char* string_lookup_table[] = {
    "EM0", "EM1", "EM2", "EM3", "EM4",
};
#include "sleepyTimers_HW.h"
void my_events_callback(sl_power_manager_em_t from, sl_power_manager_em_t to) {
    app_log_debug("Event:%s-%s\r\n", string_lookup_table[from], string_lookup_table[to]);
    uint64_t delay = SLP_getSystemTickInMs() + 1000;
    uint64_t now;
    do {
        now = SLP_getSystemTickInMs();
    } while (now < delay);
}

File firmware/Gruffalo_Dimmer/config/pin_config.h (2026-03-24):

#ifndef PIN_CONFIG_H
#define PIN_CONFIG_H

// $[CMU]
// [CMU]$

// $[LFXO]
// [LFXO]$

// $[PRS.ASYNCH0]
// [PRS.ASYNCH0]$

// $[PRS.ASYNCH1]
// [PRS.ASYNCH1]$

// $[PRS.ASYNCH2]
// [PRS.ASYNCH2]$

// $[PRS.ASYNCH3]
// [PRS.ASYNCH3]$

// $[PRS.ASYNCH4]
// [PRS.ASYNCH4]$

// $[PRS.ASYNCH5]
// [PRS.ASYNCH5]$

// $[PRS.ASYNCH6]
// [PRS.ASYNCH6]$

// $[PRS.ASYNCH7]
// [PRS.ASYNCH7]$

// $[PRS.ASYNCH8]
// [PRS.ASYNCH8]$

// $[PRS.ASYNCH9]
// [PRS.ASYNCH9]$

// $[PRS.ASYNCH10]
// [PRS.ASYNCH10]$

// $[PRS.ASYNCH11]
// [PRS.ASYNCH11]$

// $[PRS.SYNCH0]
// [PRS.SYNCH0]$

// $[PRS.SYNCH1]
// [PRS.SYNCH1]$

// $[PRS.SYNCH2]
// [PRS.SYNCH2]$

// $[PRS.SYNCH3]
// [PRS.SYNCH3]$

// $[GPIO]
// GPIO EM4WU7 on PC05
#ifndef GPIO_EM4WU7_PORT                        
#define GPIO_EM4WU7_PORT                         SL_GPIO_PORT_C
#endif
#ifndef GPIO_EM4WU7_PIN                         
#define GPIO_EM4WU7_PIN                          5
#endif

// GPIO EM4WU8 on PC07
#ifndef GPIO_EM4WU8_PORT                        
#define GPIO_EM4WU8_PORT                         SL_GPIO_PORT_C
#endif
#ifndef GPIO_EM4WU8_PIN                         
#define GPIO_EM4WU8_PIN                          7
#endif

// [GPIO]$

// $[TIMER0]
// TIMER0 CC0 on PB01
#ifndef TIMER0_CC0_PORT                         
#define TIMER0_CC0_PORT                          SL_GPIO_PORT_B
#endif
#ifndef TIMER0_CC0_PIN                          
#define TIMER0_CC0_PIN                           1
#endif

// TIMER0 CC1 on PB02
#ifndef TIMER0_CC1_PORT                         
#define TIMER0_CC1_PORT                          SL_GPIO_PORT_B
#endif
#ifndef TIMER0_CC1_PIN                          
#define TIMER0_CC1_PIN                           2
#endif

// TIMER0 CC2 on PB03
#ifndef TIMER0_CC2_PORT                         
#define TIMER0_CC2_PORT                          SL_GPIO_PORT_B
#endif
#ifndef TIMER0_CC2_PIN                          
#define TIMER0_CC2_PIN                           3
#endif

// [TIMER0]$

// $[TIMER1]
// [TIMER1]$

// $[TIMER2]
// [TIMER2]$

// $[TIMER3]
// [TIMER3]$

// $[TIMER4]
// [TIMER4]$

// $[USART0]
// [USART0]$

// $[USART1]
// [USART1]$

// $[I2C1]
// [I2C1]$

// $[PDM]
// [PDM]$

// $[LETIMER0]
// [LETIMER0]$

// $[IADC0]
// [IADC0]$

// $[I2C0]
// [I2C0]$

// $[EUART0]
// EUART0 RX on PB00
#ifndef EUART0_RX_PORT                          
#define EUART0_RX_PORT                           SL_GPIO_PORT_B
#endif
#ifndef EUART0_RX_PIN                           
#define EUART0_RX_PIN                            0
#endif

// EUART0 TX on PA00
#ifndef EUART0_TX_PORT                          
#define EUART0_TX_PORT                           SL_GPIO_PORT_A
#endif
#ifndef EUART0_TX_PIN                           
#define EUART0_TX_PIN                            0
#endif

// [EUART0]$

// $[PTI]
// [PTI]$

// $[MODEM]
// [MODEM]$

// $[CUSTOM_PIN_NAME]
#ifndef _PORT                                   
#define _PORT                                    SL_GPIO_PORT_A
#endif
#ifndef _PIN                                    
#define _PIN                                     0
#endif




#ifndef LED1_PORT                               
#define LED1_PORT                                SL_GPIO_PORT_A
#endif
#ifndef LED1_PIN                                
#define LED1_PIN                                 4
#endif

#ifndef LED2_PORT                               
#define LED2_PORT                                SL_GPIO_PORT_A
#endif
#ifndef LED2_PIN                                
#define LED2_PIN                                 5
#endif

#ifndef quad1_0_PORT                            
#define quad1_0_PORT                             SL_GPIO_PORT_A
#endif
#ifndef quad1_0_PIN                             
#define quad1_0_PIN                              6
#endif

#ifndef quad1_1_PORT                            
#define quad1_1_PORT                             SL_GPIO_PORT_A
#endif
#ifndef quad1_1_PIN                             
#define quad1_1_PIN                              7
#endif



#ifndef PWM2_PORT                               
#define PWM2_PORT                                SL_GPIO_PORT_B
#endif
#ifndef PWM2_PIN                                
#define PWM2_PIN                                 1
#endif

#ifndef PWM1_PORT                               
#define PWM1_PORT                                SL_GPIO_PORT_B
#endif
#ifndef PWM1_PIN                                
#define PWM1_PIN                                 2
#endif

#ifndef PWM0_PORT                               
#define PWM0_PORT                                SL_GPIO_PORT_B
#endif
#ifndef PWM0_PIN                                
#define PWM0_PIN                                 3
#endif





#ifndef quad0_0_PORT                            
#define quad0_0_PORT                             SL_GPIO_PORT_C
#endif
#ifndef quad0_0_PIN                             
#define quad0_0_PIN                              3
#endif
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

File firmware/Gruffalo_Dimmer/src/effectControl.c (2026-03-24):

/**
 * @file effectControl.c
 * @author Joel Santos (jsantosrico@gmail.com)
 * @brief Implementation of the LED effect control loop and animation logic.
 * @version 0.1
 * @date 2026-03-13
 * * @copyright Copyright (c) 2026
 * * @details
 * Implements the core logic for the LED state machine. Key implementation
 * details include:
 * * **Control Loop:** The @ref effectControlLoop is designed to be triggered
 * by a TIMER0 overflow interrupt, running at the PWM frequency to ensure
 * glitch-free updates.
 * * **Smooth Transitions:** Employs a ramp-up/down mechanism that adjusts
 * the compare value by 1 on each PWM cycle until the target brightness
 * is reached.
 * * **Persistence:** Maintains the state of each LED channel (target
 * brightness, current animation, and timing) in internal `LED_t`
 * structures.
 */

#include "effectControl.h"

// StdLib
#include <math.h>

// SiLabs headers
#include "app_assert.h"
#include "app_log.h"

// Our Libs
#include "PWMControl.h"

// Little trick to test static stuff
#ifdef TEST
#define STATIC
#else
#define STATIC static
#endif

////
// Consts and static stuff
////

/**
 * @brief The number of LED channels, set by HW
 */
const uint32_t NUM_LED_CHANNELS = 3UL;

/**
 * @brief The LED brightness at startup
 */
const uint32_t DEFAULT_LED_BRIGHTNESS = 5000UL;

/**
 * @brief The minimum and default values for the breathe period, in ms
 */
const uint32_t BREATHE_MIN_PERIOD_MS     = BREATHE_LUT_SIZE;
const uint32_t BREATHE_DEFAULT_PERIOD_MS = 5000;

/**
 * @brief Default values for the breathe effect
 */
const uint32_t BREATHE_MAX_BRIGHTNESS = MAX_BRIGHTNESS;
const uint32_t BREATHE_MIN_BRIGHTNESS = 1000;  // 10%
const double BREATHE_BETA             = 0.5L;  // peak at half the period
const double BREATHE_GAMMA            = .15L;

/**
 * @brief Contains the pre-calculated values for the breathe effect brightness levels. uint16_t as it contains a percent value
 * with 2 significative numbers (10000 = 100.00%)
 */
STATIC uint32_t gausianBreatheLUT[BREATHE_LUT_SIZE] = {0UL};

/**
 * @brief Default parameters of the breathe effect, in case none are provided
 *
 */
const breatheParams_t DEFAULT_BREATHE_PARAMS = {.maxBrightness = BREATHE_MAX_BRIGHTNESS,
                                                .minBrightness = BREATHE_MIN_BRIGHTNESS,
                                                .beta = BREATHE_BETA,  // set the breathe effect peak at half the period
                                                .gamma   = BREATHE_GAMMA,
                                                .LUTSize = BREATHE_LUT_SIZE};

// Instances of LED Strips
STATIC LED_t LEDCh1 = {.currAnimation = ANIM_FIXED};
STATIC LED_t LEDCh2 = {.currAnimation = ANIM_FIXED};
STATIC LED_t LEDCh3 = {.currAnimation = ANIM_FIXED};

/**
 * @brief Fills the breateh effect LUT with the correct parameters as specified by effectParams
 * @param effectParams_ptr a pointer to a breatheParams_t struct with the parameters of the breathe effect
 */
void fillBreatheEffectLUT(const breatheParams_t* effectParams_ptr) {
    if (effectParams_ptr != NULL) {
        for (uint32_t i = 0; i < effectParams_ptr->LUTSize; i++) {
            float aux = effectParams_ptr->minBrightness +
                        (effectParams_ptr->maxBrightness - effectParams_ptr->minBrightness) *
                            exp(-(pow(((float)i / effectParams_ptr->LUTSize) - effectParams_ptr->beta, 2.0L) /
                                  (2 * pow(effectParams_ptr->gamma, 2.0L))));
            gausianBreatheLUT[i] = (uint16_t)lroundf(aux);
        }
    }
}

/**
 * @brief Initialises the LED structs. Because the HW is fixed, we can also fix the memory and do everything inside
 * the function without having to pass anything.
 * @param LED_ptr
 * @return
 */
efferr_t initLEDStrips(void) {
    // No need to pass anything to it as we are initting all the strips we have to default values
    LED_t* channels[3] = {&LEDCh1, &LEDCh2, &LEDCh3};
    // breatheControl_t* breatheCtrlArray[3] = {&breatheCh1, &breatheCh2, &breatheCh3};
    // brightnessControl_t* brightnessCtrlArray = {&brightnessCh1, &brightnessCh2, &brightnessCh3};

    for (uint32_t i = 0; i < NUM_LED_CHANNELS; i++) {
        // Get next pointer fron the list of channels
        LED_t* currChannel_ptr = channels[i];
        // Set animation to fixed brightness
        currChannel_ptr->currAnimation = ANIM_FIXED;
        // Set brightness to starting default, and set the brightness Change Request Flag
        currChannel_ptr->brightnessCtrl.targetBrightness          = DEFAULT_LED_BRIGHTNESS;
        currChannel_ptr->brightnessCtrl.delta                     = 0;  // will be calculated in the effect control loop
        currChannel_ptr->brightnessCtrl.brightChangeRequestedFlag = true;
        // Set PWM period from clock. multiplied by 1000 to get ms
        currChannel_ptr->pmwPeriodms = 1000UL / (getPWMFrequency());
        // Assert if the PWM period is 0, as that we use it as  a divisor!
        app_assert(currChannel_ptr->pmwPeriodms != 0, "\r\nPWM Period is %" PRIu32 "!", currChannel_ptr->pmwPeriodms);
        // Init breatheControl_t for that LED, set to 0 as we are starting with fixed brightness
        currChannel_ptr->breatheCtrl.periodms       = 0;
        currChannel_ptr->breatheCtrl.wavesPerSample = 0;
        currChannel_ptr->breatheCtrl.currWave       = 0;
        currChannel_ptr->breatheCtrl.currLUTIndex   = 0;
    }

    setBreathePeriod(LED_CHANNEL_1, BREATHE_DEFAULT_PERIOD_MS);
    setBreathePeriod(LED_CHANNEL_2, BREATHE_DEFAULT_PERIOD_MS);
    setBreathePeriod(LED_CHANNEL_3, BREATHE_DEFAULT_PERIOD_MS);

    // Link LEDs and PWM channels
    LEDCh1.CCChannel = CC_CHANNEL_0;
    LEDCh2.CCChannel = CC_CHANNEL_1;
    LEDCh3.CCChannel = CC_CHANNEL_2;

    return EFF_OK;
}

/**
 * @brief Returns a pointer to the LED struct for the desired channel
 * @param channelNo the channel which LED struct we want to retrieve
 * @return a pointer to the LED_t struct of the channel passed as parameter. On wrong channel, defaults to LED Ch 1
 */
LED_t* getLEDStruct(const LEDChannel_t channelNo) {
    LED_t* LED_ptr = NULL;
    switch (channelNo) {
        case LED_CHANNEL_2: {
            LED_ptr = &LEDCh2;
            break;
        }
        case LED_CHANNEL_3: {
            LED_ptr = &LEDCh3;
            break;
        }
        case LED_CHANNEL_1: /* fallthrough */
        default: {
            // Default, on wrong channel, return Ch 1
            LED_ptr = &LEDCh1;
            break;
        }
    }
    return LED_ptr;
}

/**
 * @brief Get the name of the current Effect as a string
 * @param effectType a type of effect
 * @return char* a null terminated string with the name of the effect
 */
char* getEffectName(const anim_t effectType) {
    switch (effectType) {
        case ANIM_BREATHE: {
            return "Breathe Effect";
        }
        case ANIM_FIXED: /* fall-through */
        default: {
            return "Fixed Brightness";
        }
    }
}
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

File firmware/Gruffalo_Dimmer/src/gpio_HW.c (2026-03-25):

/**
 * @file gpio_HW.c
 * @author Joel Santos (jsantosrico@gmail.com)
 * @brief Implementation of Silicon Labs specific GPIO hardware wrappers.
 * @version 0.1
 * @date 2026-03-13
 * * @copyright Copyright (c) 2026
 * * @details
 * Implements the translation layer between the project's generic GPIO API and
 * the `em_gpio` SDK.
 * * ### Internal Logic
 * * **Port Mapping:** The `getSiLabsPort` helper ensures that only ports
 * physically present on the BGM220P (Ports A through D) are utilized,
 * triggering @ref app_assert on invalid port requests.
 * * **EM4 Wake-up:** Hard-codes the specific pin/port combinations (e.g., PC05
 * for EM4WU7) that are hardware-capable of waking the core from deep sleep.
 * * **Safety:** Uses diagnostic pragmas to suppress cast-alignment warnings
 * common in vendor-provided CMSIS headers.
 */
#include "gpio_HW.h"

// Silabs SDK headers
#include "app_assert.h"
#include "em_cmu.h"
#include "em_gpio.h"

#ifdef TEST
#define STATIC
#else  // TEST
#define STATIC static
#endif  // TEST

////
// Getters to translate from our enums to the SiLabs's ones
////

/**
 * @brief Translates from our port enum to the Silabs's one
 * @param port the gpio port as a pinport_t
 * @return the equivalent GPIO_Port_TypeDef pin port
 */
STATIC GPIO_Port_TypeDef getSiLabsPort(pinPort_t port) {
    switch (port) {
        case portA: {
            return gpioPortA;
        }
        case portB: {
            return gpioPortB;
        }
        case portC: {
            return gpioPortC;
        }
        case portD: {
            return gpioPortD;
        }
        case portE: {
            app_assert(false, "Port E doesn't have pins in the BGM220P");
            break;
        }
        case portF: {
            app_assert(false, "Port F doesn't have pins in the BGM220P");
            break;
        }
        default: {
            break;  // do nothing, fall through and assert
        }
    }
    app_assert(false, "Unknown port");
    return 0;  // wil never return 0, it should assert
}

/**
 * @brief Translates from our pin mode to the Silabs's one
 * @param mode the pin mode as a pinMode_t
 * @return the equivalent GPIO_Mode_TypeDef pin mode
 */
STATIC GPIO_Mode_TypeDef getSiLabsMode(pinMode_t mode) {
    // NOTE: I'll only do this for now, but add more if needed!
    switch (mode) {
        case MODE_DISABLED: {
            return gpioModeDisabled;
        }
        case MODE_INPUT: {
            return gpioModeInput;
        }
        case MODE_INPUT_PULL: {
            return gpioModeInputPull;
        }
        case MODE_INPUT_PULL_FILTER: {
            return gpioModeInputPullFilter;
        }
        case MODE_PUSHPULL: {
            return gpioModePushPull;
        }
        default: {
            break;
        }
    }
    app_assert(false, "Unknown pin mode");
    return gpioModeDisabled;  // should never return this, will assert first
}

////
// Wrapper Functions
////

/**
 * @brief Enables the GPIO clock
 * NOTE: If a module clock is disabled, the registers of that module are not accessible and accessing such registers
 * will hardfault the Cortex core.
 *
 */
void enableGPIOClock(void) { CMU_ClockEnable(cmuClock_GPIO, true); }

/**
 * @brief Set a pin Up (Wrapper for GPIO_PinModeSet)
 * @param port the pin port
 * @param pin the pin number
 * @param mode the pin mde
 * @param dout the value for the Out register
 */
void setPinMode(pinPort_t port, uint8_t pin, pinMode_t mode, bool dout) {
    GPIO_PinModeSet(getSiLabsPort(port), pin, getSiLabsMode(mode), dout);
}

/**
 * @brief Reads an input pin's value
 * @param port the pin port
 * @param pin the pin number
 * @return uint32_t the current state of the pin, 0 if clear and 1 if set
 */
uint32_t readPin(pinPort_t port, uint8_t pinNo) { return GPIO_PinInGet(getSiLabsPort(port), pinNo); }

/**
 * @brief Sets the state of an output pin
 *
 * @param port the pin's port
 * @param pinState_t newState the new state for the pin
 * @param pinNo the pin's number
 */
void writePin(pinPort_t port, uint8_t pinNo, pinState_t newState) {
    // This function takes a mask as pinNo, so you can set as many pins on the port as you want, but we are limiting it
    // to one here to make things simpler (otherwise I have to pass a mask, instead of a pin number)
    GPIO_PortOutSetVal(getSiLabsPort(port), (uint8_t)newState, pinNo);
}

/**
 * @brief Configures a GPIO interrupt
 * @param port the port of the pin to read
 * @param pinNo the number of pin to read
 * @param intNo the number of interrupt to register
 * @param risingEdge enable interrupt in Rising Edge
 * @param fallingEdge enable interrupt in falling Edge
 * @param enable true to enable the interrupt or false to leave it disabled.
 */
void configurePinInterrupt(pinPort_t port, uint8_t pinNo, uint32_t intNo, bool risingEdge, bool fallingEdge,
                           bool enable) {
    GPIO_ExtIntConfig(getSiLabsPort(port), pinNo, intNo, risingEdge, fallingEdge, enable);
}
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

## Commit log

2020-10-30 Added HW. First Spin at OSH Park
    [Header 2x05 - 0.005in - SMD -Amphenol 20021121-00010XXLFc v3.step, Placeholder v2.step, SOT23-3 v1.step]
2022-11-11 Basic handling of one rotary encoder via interrutps
2022-11-18 Working buttons and rotary encoder with debouncing for the buttons and as much as possible unit tested!
2022-11-22 App with buttons working (only encoder 1). 100% unit tested
2022-11-27 Extracted types defined by the *_HW headers to their own .h files, now they can be included in other headers for function declaration without making testing impossible!! First stab at generating and 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
2022-12-08 WIP Unit testing what we have so far to link to Ceedling issue in github
    [PWMControl.c, app.c, buttonActions.c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]
2023-02-10 Updated HW to KiCad. Most Done, only graphics left
    [Encoder.kicad_sch, Header 2x05 - 0.005in - SMD -Amphenol 20021121-00010XXLFc v3.step, LED_Dimmer.kicad_pcb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]
2023-02-10 WIP - Made lots of changes, then didn't commit for 2 months, and deleted the project. Had to restore from sharepoint. I think I'm back to where I was. At least test run and the project compiles. Big 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
    [PWMControl.c, app.c, buttonActions.c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]
2023-03-02 v2 Board Ready - Added Art - Removed DRC/ERC - Finished BOM
    [Encoder.kicad_sch, LED_Dimmer.kicad_pcb, LED_Dimmer.kicad_sch]
2023-03-02 PCB art
2023-06-28 Getting ready for KiBot. Removed some old references to 3D models from some parts
    [Encoder.kicad_sch, LED_Dimmer.kicad_pcb, LED_Dimmer.kicad_sch]
2023-07-03 Changed the 3D model of the diode to an externally-added STEP file Removed Refs from potentiometers
    [LED_Dimmer.kicad_pcb]
2023-10-22 Not sure of the complete list of changes, but fixed a bunch of DRC/ERC errors
    [Encoder.kicad_sch, LED_Dimmer.kicad_pcb, LED_Dimmer.kicad_sch]
2023-10-23 CI/CD set up
    [LED_Dimmer.kicad_pcb]
2023-10-23 Minor fix: forgot to update model after changing 3D model
    [LED_Dimmer.kicad_pcb]
2023-10-23 remove some warnings and errors from CICD
    [LED_Dimmer.kicad_pcb]
2023-10-24 Changed a digikey PN and removed the gruffalo art from the BOM
    [LED_Dimmer.kicad_sch]
2023-11-10 Added some parts to the BoM that are not on the board (connector receptacle, crimps) Checked status of MPNs, and removed some old ones
    [KiCost.xlsx, LED_Dimmer.kicad_sch]
2024-09-13 Updated HW Files to KiCad 8.0
    [Encoder.kicad_sch, LED_Dimmer.kicad_sch]
2024-09-19 Reenabled the FEM (didn't need to disable, it seems)
    [sl_event_handler.c]
2024-09-25 Latest WIP, still stuck in RTCC_SyncWait()
    [em_gpio.h, pin_config.h]
2024-09-27 WIP, found the timer overflow error, working on it
    [app.c, buttonActions.c, buttons.c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]
2024-10-04 WIP Changed timer struct to incomplete type to fix overflow
    [app.c, buttons.c]
2024-10-18 Buttons work now, but quad doesn't. Need to check the HW Updated Ceedling to latest version, tests are now passing!
    [PWMControl.c, app.c, buttonActions.c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]
2024-10-23 Renamed some functions that are generic and not need a pin number on them
2024-10-31 Moved "percentage" to int
    To avoid weird cases where negatives roll to 255
    [PWMControl.c]
2024-11-15 Got PWM working in the three channels
    Not entirely happy with things, need to clean a bit and change the way the next count is fed to the CC module, but it works!
2024-11-29 Hotfix: Bug enabling timers
    [timer_HW.c]
2025-11-24 Updated to KiCad 9
    - Changed LED Connectors to Kyocera
    - Made board bigger
    - Made art better and bigger
    - Micro breakout now has header pins outside (easier to solder)
    [Encoder.kicad_sch, LED_Dimmer.kicad_sch]
2025-12-04 99% there
    Board is almost ready for new spin, but a couple of bugs exporting the 3D model of the board require custom 3D models and I'm not superhappy with that. Waiting for them to get fixed, but might take months
2025-12-11 KiBot Config Udpdated to KiCad9
    [LED_Dimmer.kicad_sch]
2026-02-03 Fixed Generators in VSCode
    [PWMControl.c, app.c, buttonActions.c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]
2026-02-08 Fixed Brightness Looks Good!
    [PWMControl.c, app.c, buttonActions.c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]
2026-02-13 Button 1 changes animation mode
2026-02-15 Linked LEDs to PWM channels, instead of relying on a function to get it
2026-02-16 Moved to Up-Down, as I think it will work better. Fixed interrupts as I was using the wrong ones as drivers
    [PWMControl.c, timer_HW.c]
2026-02-16 Breathe at fixed period and brightness
    [app.c, effectControl.c, test_effectControl.c]
2026-02-17 Can change breathe effect period with encoder (plus added asserts to tests)
2026-02-20 Connected buttons to EM4 wake up pins
    [LED_Dimmer.kicad_sch]
2026-02-26 Refactored to one single function to start timers to reduce code duplication
2026-02-26 Refactored Debounce to use one clock
    [gcovr.cfg]
2026-02-27 And more refactoring! debounce shouldn't be starting and stopping button timers
2026-03-04 Added Kyocera Connector
    [Encoder.kicad_sch, LED_Dimmer.kicad_sch]
2026-03-04 Updated Rotary Encoder 3d Model
2026-03-05 Improved GPIO and added set pin for EM4 wake
2026-03-09 Tweaked positions of encoders, smd passive shapes, and rerouted
    [Encoder.kicad_sch]
2026-03-11 Proper way to turn LEDS off before entering sleep
2026-03-16 Changed board origin to centre of pcb
2026-03-18 Added LED Indicators
    [Encoder.kicad_sch, LED_Dimmer.kicad_sch]
2026-03-24 Not sure what I did here ¯\_(ツ)_/¯
2026-03-24 Added LED indicator pins
2026-03-24 Changes for LED indicator
2026-03-25 LED Channel Selected Indicators
2026-04-14 Regulator pinout was wrong! Also decoupling cap was not decoupling
    [Encoder.kicad_sch, LED_Dimmer.kicad_sch]
